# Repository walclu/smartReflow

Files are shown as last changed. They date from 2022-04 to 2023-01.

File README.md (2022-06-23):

# smartReflow
## Repository for STM32WB55 based reflow toaster oven controller

The smartReflowV2 is a STm32WB55 based toaster oven reflow controller for reflowing PCBs at home. 

## Features
- 2 SSR outputs
- 2 cooling fan outputs
- 2 MAX31855 temperature ADCs
- Buzzer
- Touch screen (Nextion 2.4" UART Display)
- Bluetooth low energy, onboard chip antenna with matching
- 2 virtual com ports 
- MATLAB data streaming
- EEPROM for storing custom profiles
- PLA drying mode

## Assembly
The PCB was made by JLCPCB and assembled by hand.
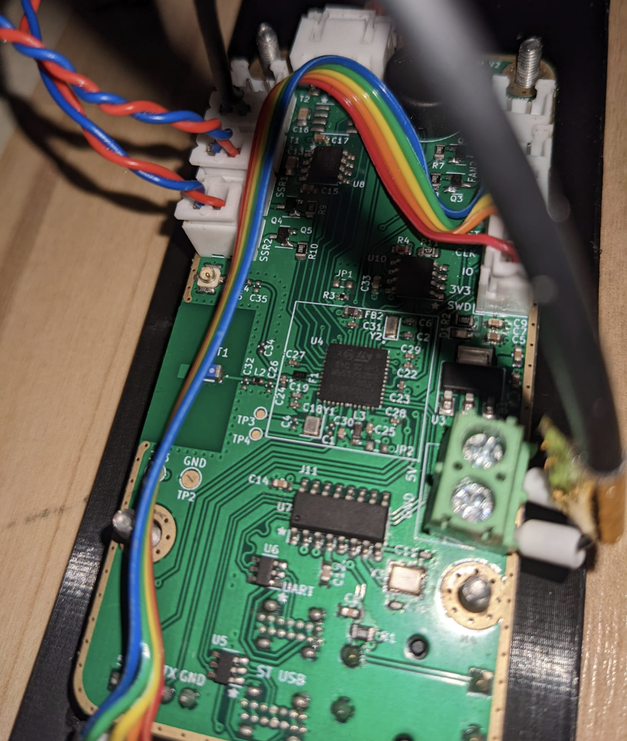
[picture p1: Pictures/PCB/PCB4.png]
Assembled PCB


## Results
The oven follows the desired temperature profile with only 5% of total error (Reflow state is a little bit delayed at the end).
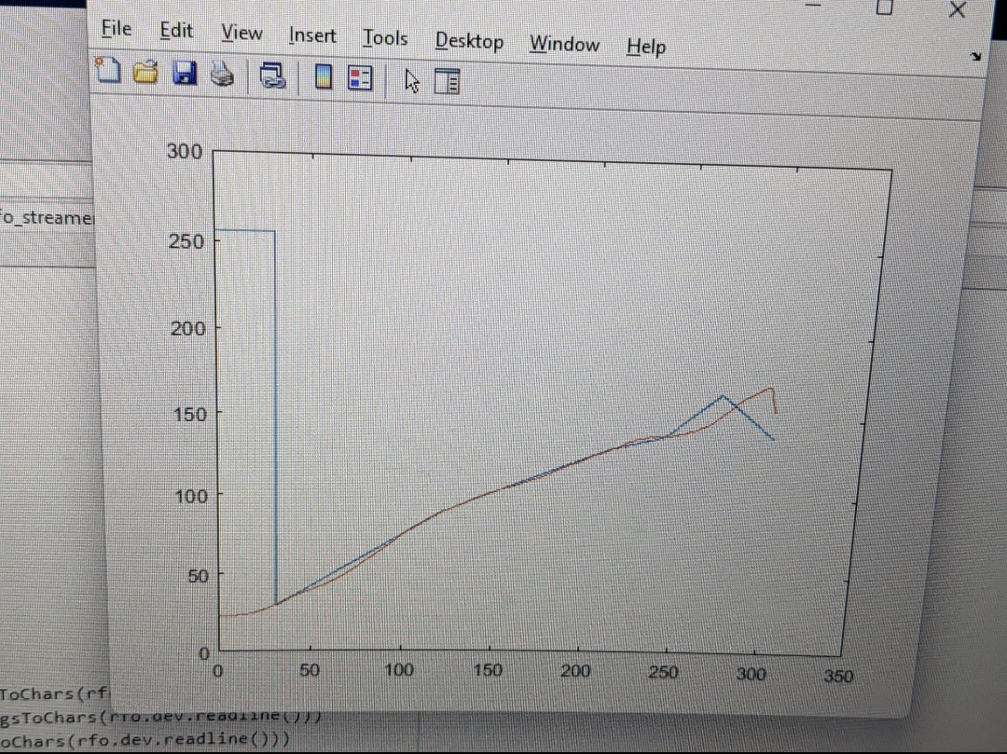
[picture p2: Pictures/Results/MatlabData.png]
matlab

QFN28 soldering results with 138 C paste profile. No need of rework had to be done.
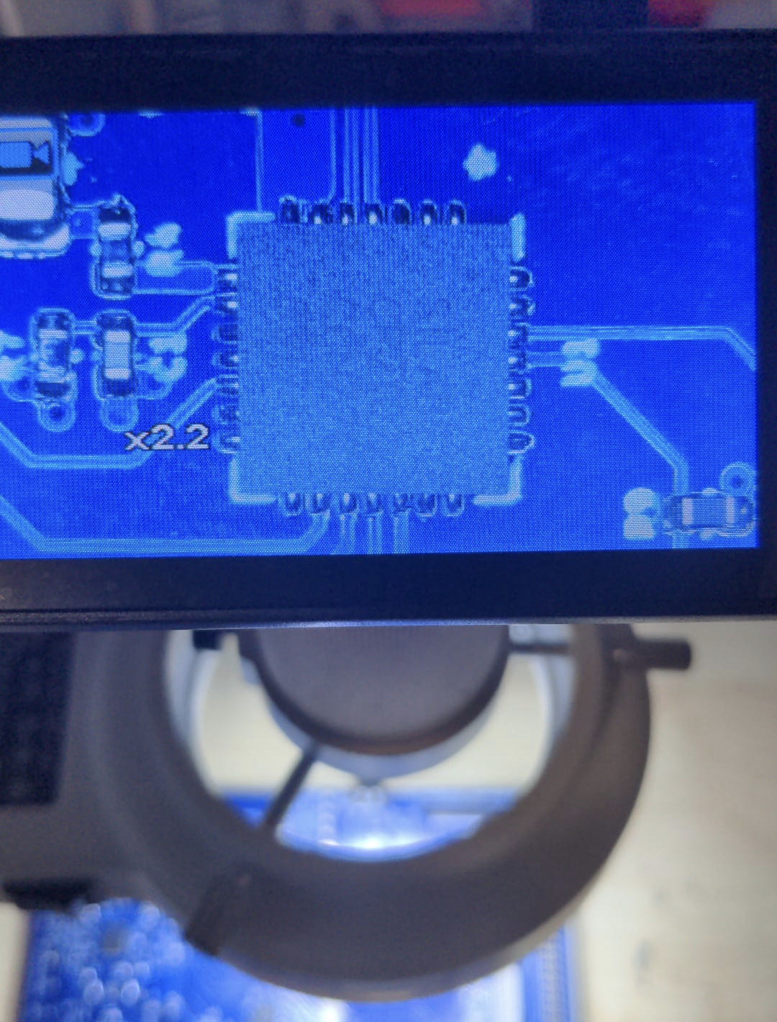
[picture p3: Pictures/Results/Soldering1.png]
qfn soldering

Finished oven
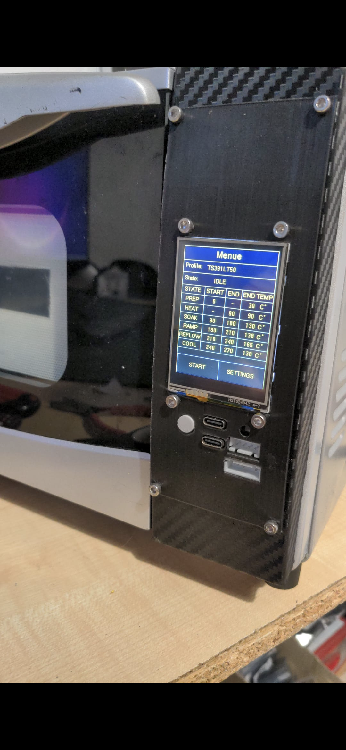
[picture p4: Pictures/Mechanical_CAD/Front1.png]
Oven front


## ToDos
- Bluetooth works, but an interface (i.e. app) is needed
- Firmware is hard to read
- PCB outline is too small (Nextion Display does not fit nicely onto it)
- EEPROM usage not implemented
- PID autotune code

## License
MIT

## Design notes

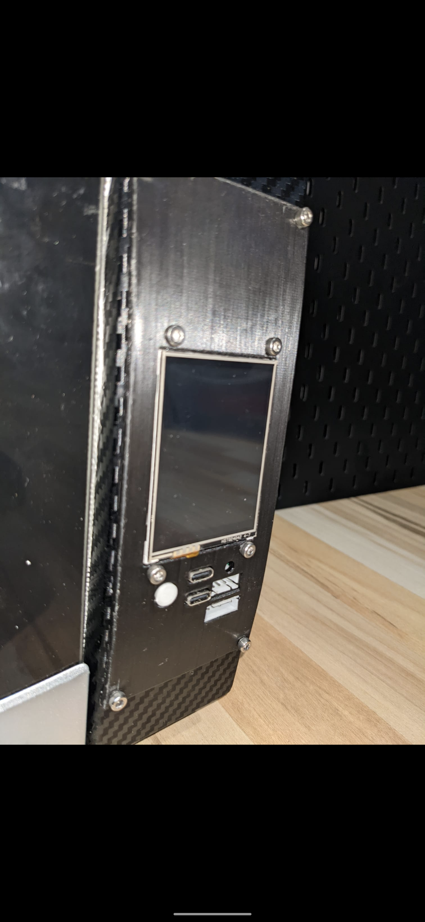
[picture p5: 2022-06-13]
Pictures/Mechanical_CAD/Front2.png

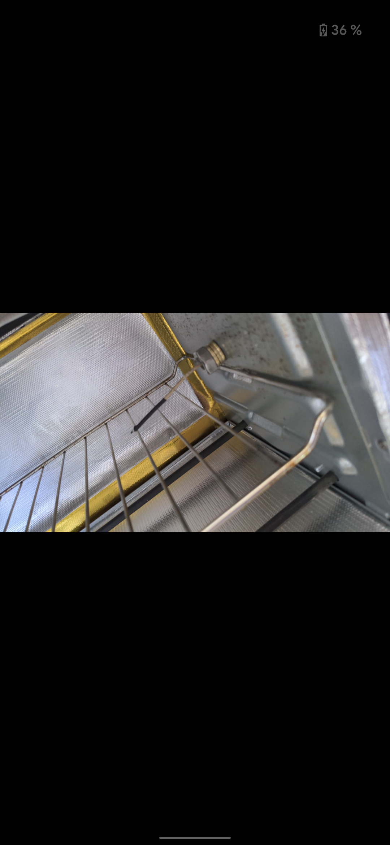
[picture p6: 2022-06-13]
Pictures/Mechanical_CAD/Tempsens.png

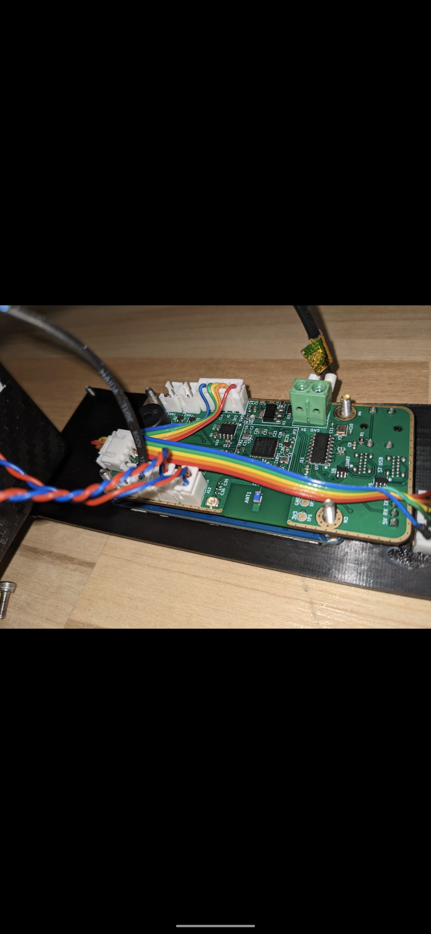
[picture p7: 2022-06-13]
Pictures/PCB/PCB3.png

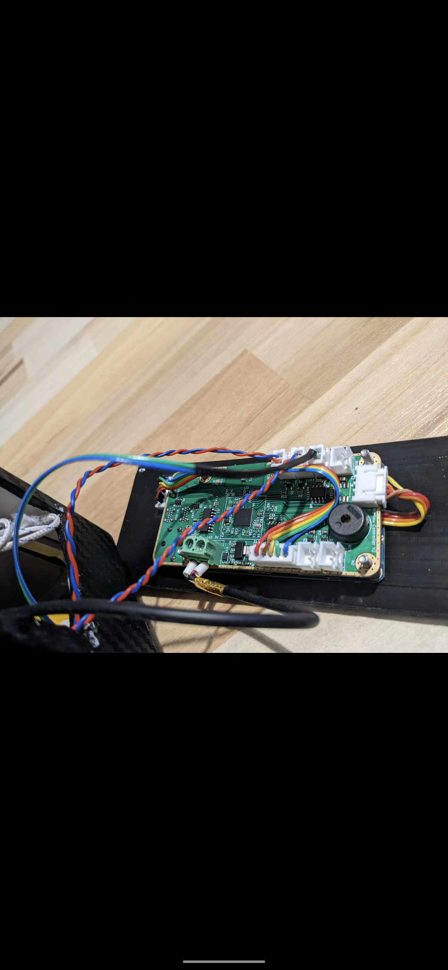
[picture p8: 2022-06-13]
Pictures/PCB/PCB5.png

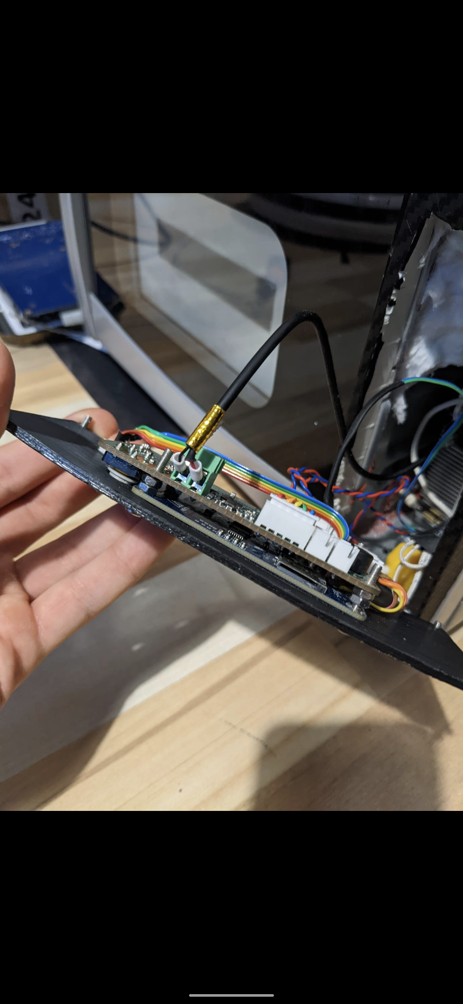
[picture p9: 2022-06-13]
Pictures/PCB/PCB7.png

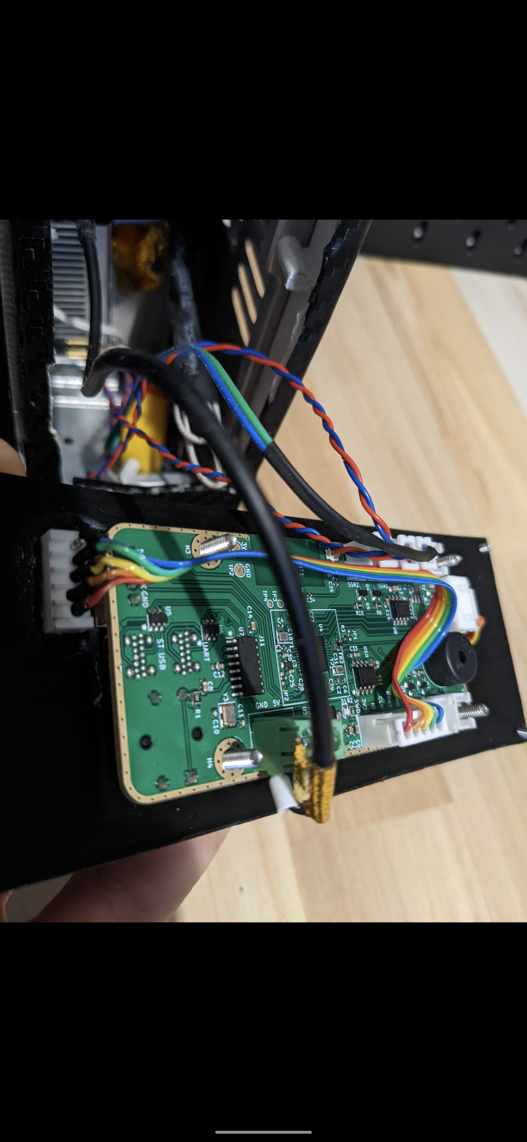
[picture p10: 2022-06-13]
Pictures/PCB/PCB6.png

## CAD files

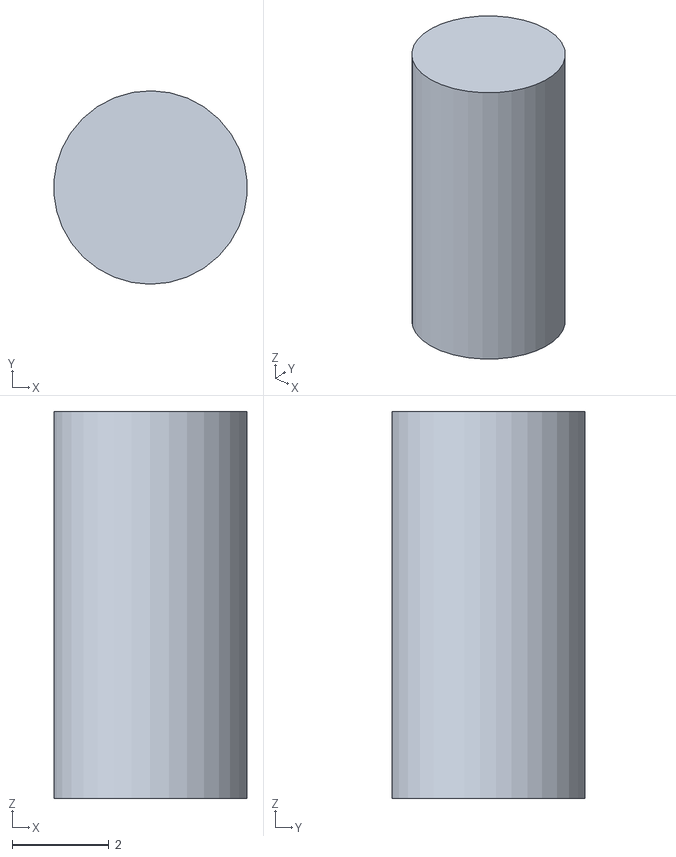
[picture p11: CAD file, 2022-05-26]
3D_CAD/led.stl
3.99 x 4.00 x 8.00

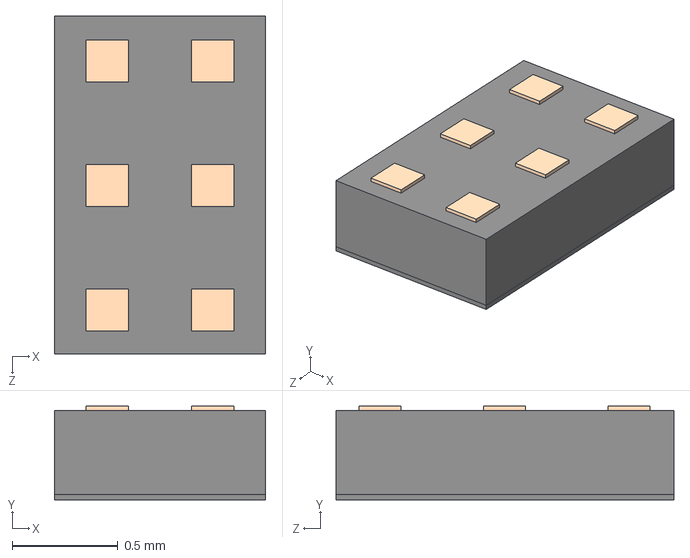
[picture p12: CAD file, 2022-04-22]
PCB/parts/rCv2LIB/3d.shapes/MLPF-WB55-01E3.stp
1.00 x 0.445 x 1.60 mm

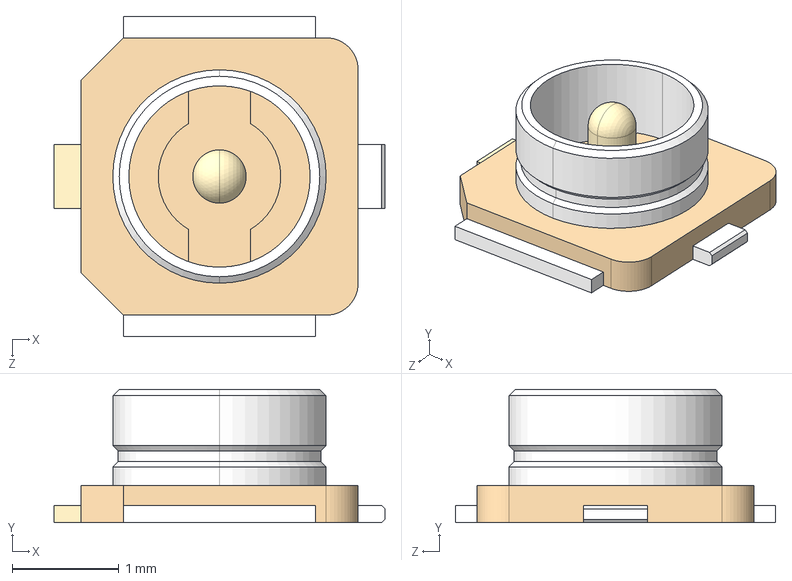
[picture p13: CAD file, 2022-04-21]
PCB/parts/rCv2LIB/A-1JB/3d.shapes/A-1JB.step
3.10 x 1.25 x 3.00 mm

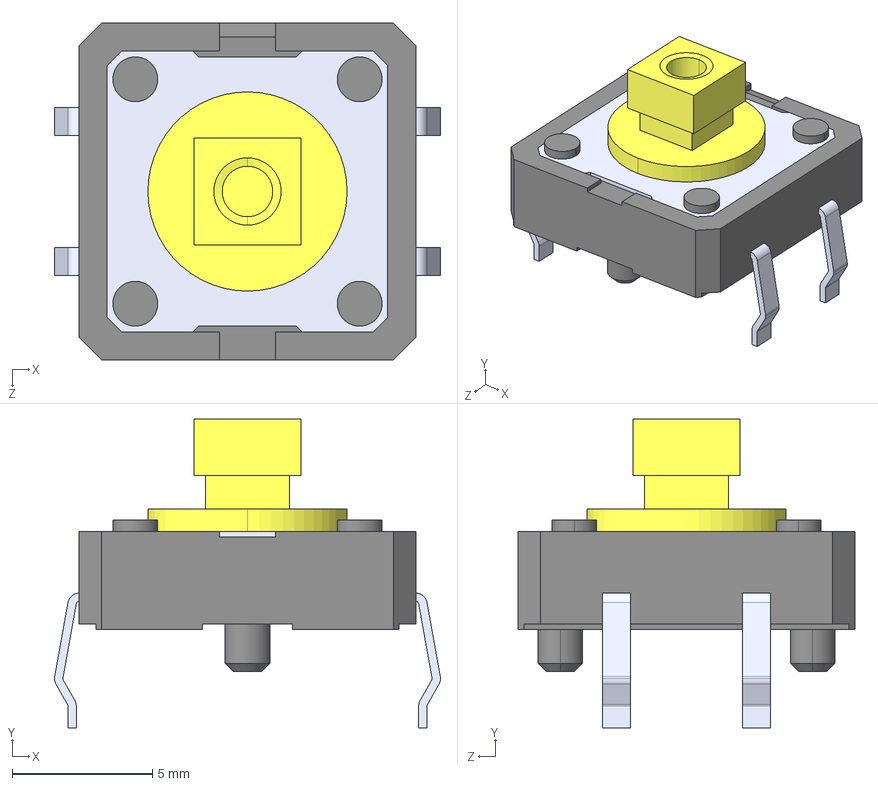
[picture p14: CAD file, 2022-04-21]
PCB/parts/rCv2LIB/B3F-4055/3d.shapes/B3F-4055.step
13.8 x 11.0 x 12.0 mm

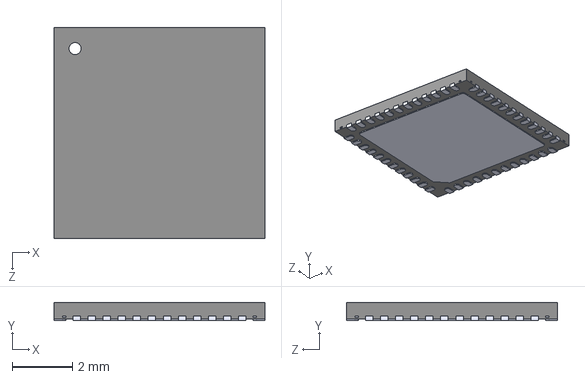
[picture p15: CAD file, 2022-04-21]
PCB/parts/rCv2LIB/STM32WB55CEU6TR/3dshapes/STM32WB55CEU6TR.step
7.00 x 0.6 x 7.00 mm

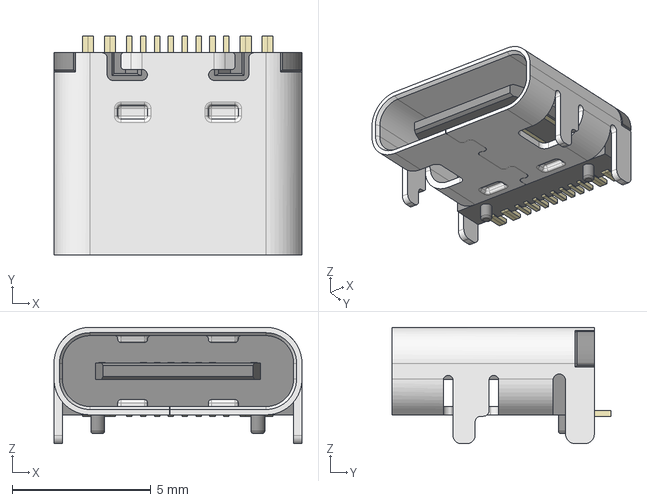
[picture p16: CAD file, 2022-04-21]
PCB/parts/rCv2LIB/TYPC/3d.shapes/HRO_TYPE-C-31-M-12.step
8.95 x 7.90 x 4.20 mm

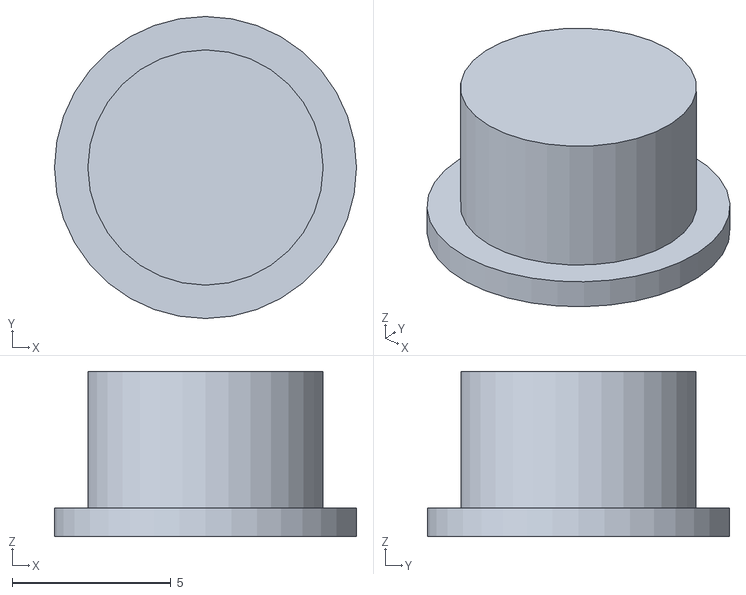
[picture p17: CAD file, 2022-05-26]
3D_CAD/button.stl
9.50 x 9.50 x 5.20

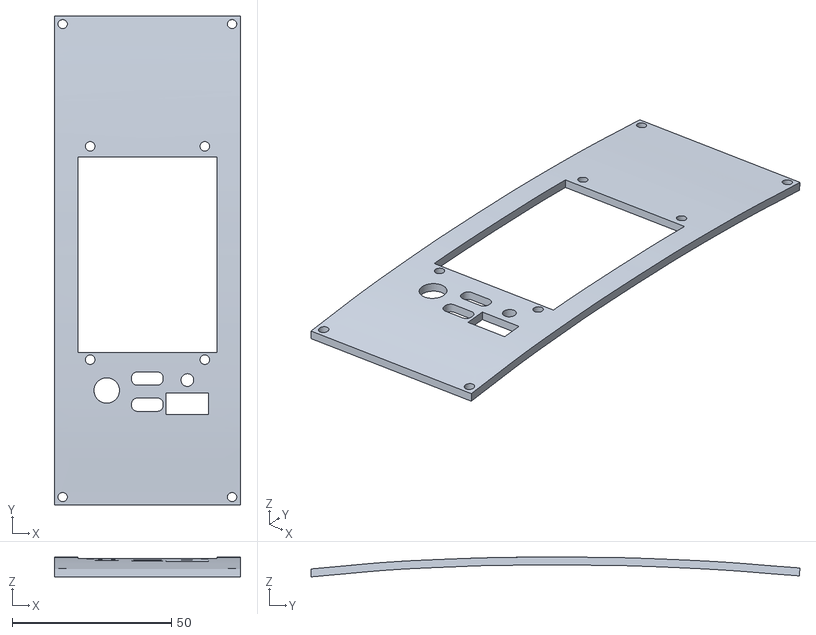
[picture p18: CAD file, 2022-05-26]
3D_CAD/smartReflowFront.stl
58.5 x 153.6 x 6.25

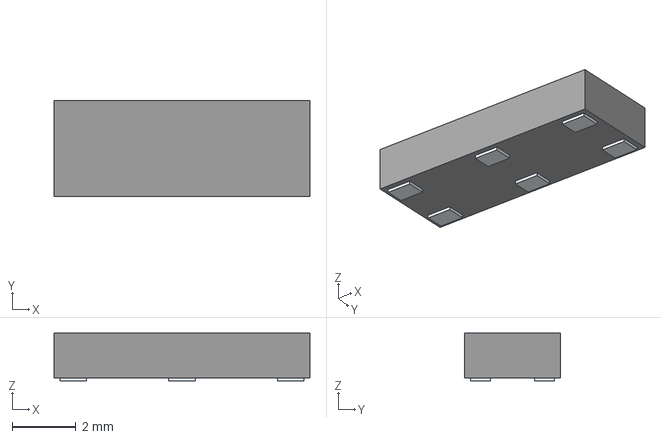
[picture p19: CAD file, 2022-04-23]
PCB/parts/rCv2LIB/M830520/3d.shapes/M830520.stp
8.00 x 3.00 x 1.50 mm
Pins

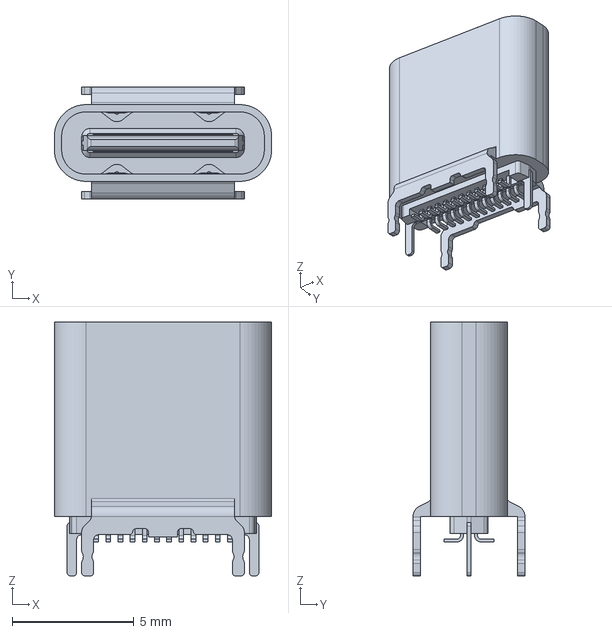
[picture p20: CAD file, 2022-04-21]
PCB/parts/rCv2LIB/3d.shapes/2047110001.stp
8.94 x 4.60 x 10.4 mm

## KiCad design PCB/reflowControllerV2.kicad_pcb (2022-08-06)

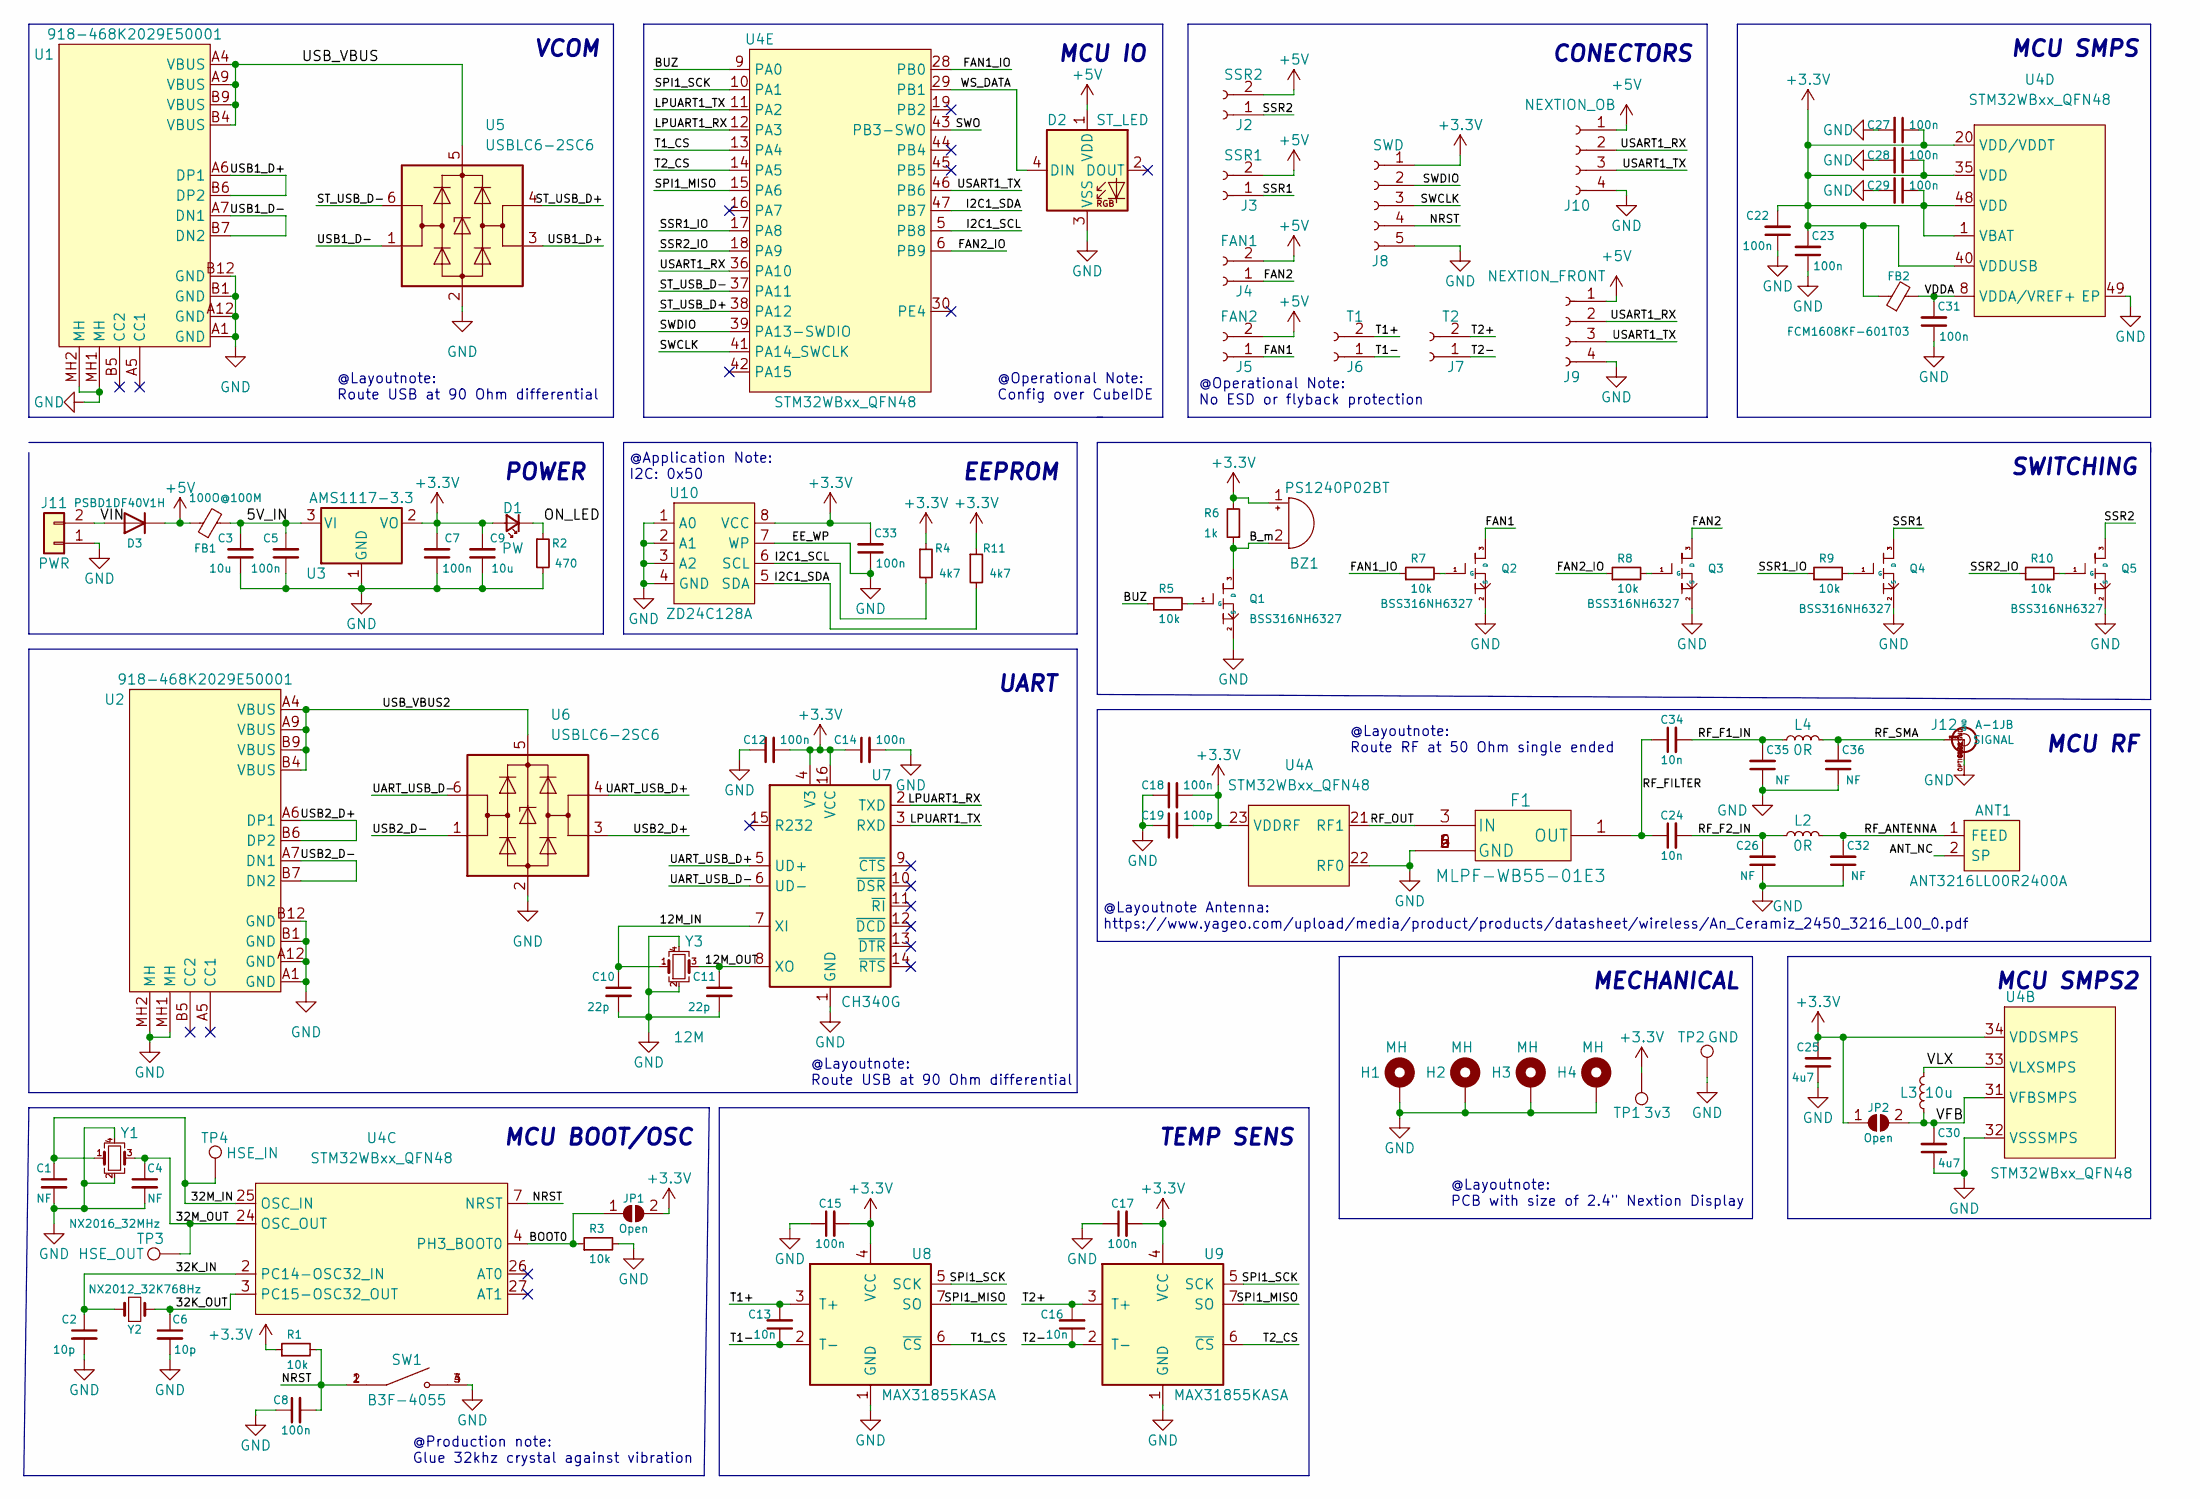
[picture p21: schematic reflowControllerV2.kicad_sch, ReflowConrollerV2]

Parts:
ANT1: ANT3216LL00R2400A; Mouser Part Number 603-ANT3216LL00R2400
BZ1: PS1240P02BT; Buzzer_TDK_PS1240P02BT_D12.2mm_H6.5mm
C1, C4, C26, C32, C35, C36: NF; C_0402_1005Metric
C2, C6: 10p; C_0402_1005Metric
C3, C9: 10u; C_0603_1608Metric
C5, C7, C8, C12, C14, C15, C17, C33: 100n; C_0603_1608Metric
C10, C11: 22p; C_0402_1005Metric
C13, C16: 10n; C_0805_2012Metric
C18, C22, C23, C27, C28, C29, C31: 100n; C_0402_1005Metric
C19: 100p; C_0402_1005Metric
C24, C34: 10n; C_0402_1005Metric
C25, C30: 4u7; C_0402_1005Metric
D1: PW; LED_0603_1608Metric
D2: ST_LED; LED_WS2812B_PLCC4_5.0x5.0mm_P3.2mm
D3: PSBD1DF40V1H; D_SOD-123F
F1: MLPF-WB55-01E3
FB1: 100O@100M; L_0603_1608Metric
FB2: FCM1608KF-601T03; L_0603_1608Metric
H1, H2, H3, H4: MH; MountingHole_3.2mm_M3_Pad_Via
J2: SSR2; JST_254_2P_V
J3: SSR1; JST_254_2P_V
J4: FAN1; JST_254_2P_V
J5: FAN2; JST_254_2P_V
J6: T1; JST_254_2P_V
J7: T2; JST_254_2P_V
J8: SWD; JST_254_5P_V
J9: NEXTION_FRONT; JST_254_4P_V
J10: NEXTION_OB; JST_254_4P_H
J11: PWR; TerminalBlock_Phoenix_MKDS-1,5-2_1x02_P5.00mm_Horizontal
J12: A-1JB; AMPHENOL_A-1JB
JP1, JP2: Open; R_0603_1608Metric
L2, L4: 0R; L_0402_1005Metric
L3: 10u; L_0603_1608Metric
Q1, Q2, Q3, Q4, Q5: BSS316NH6327; SOT-23
R1, R5, R7, R8, R9, R10: 10k; R_0603_1608Metric
R2: 470; R_0603_1608Metric
R3: 10k; R_0402_1005Metric
R4, R11: 4k7; R_0603_1608Metric
R6: 1k; R_0603_1608Metric
SW1: B3F-4055; SW_B3F-4055; PARTREV A070-E1-08
TP1: 3v3; TestPoint_Pad_D2.0mm
TP2: GND; TestPoint_Pad_D2.0mm
TP3: HSE_OUT; TestPoint_Pad_D1.0mm
TP4: HSE_IN; TestPoint_Pad_D1.0mm
U1, U2: 918-468K2029E50001
U3: AMS1117-3.3; SOT-223-3_TabPin2
U4: STM32WBxx_QFN48; QFN50P700X700X60-49N
U5, U6: USBLC6-2SC6; SOT-23-6
U7: CH340G; SOIC-16_3.9x9.9mm_P1.27mm
U8, U9: MAX31855KASA; SOIC-8_3.9x4.9mm_P1.27mm
U10: ZD24C128A; SOP-8_3.9x4.9mm_P1.27mm
Y1: NX2016_32MHz; Crystal_SMD_2016-4Pin_2.0x1.6mm
Y2: NX2012_32K768Hz; Crystal_SMD_2012-2Pin_2.0x1.2mm_HandSoldering
Y3: 12M; Crystal_SMD_3225-4Pin_3.2x2.5mm

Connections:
+3V3: BZ1.1 (-), C7.2, C9.2, C12.2, C14.1, C15.2, C17.2, C18.2, C19.2, C22.2, C23.2, C25.2, C27.1, C28.1, C29.1, C33.2, D1.2 (A), FB2.1, J8.1, JP1.2 (B), JP2.1 (A), R1.1, R4.1, R6.2, R11.1, TP1.1, U3.2 (VO), U4.1 (VBAT), U4.20 (VDD/VDDT), U4.23 (VDDRF), U4.34 (VDDSMPS), U4.35 (VDD), U4.40 (VDDUSB), U4.48 (VDD), U7.4 (V3), U7.16 (VCC), U8.4 (VCC), U9.4 (VCC), U10.8 (VCC)
+5V: D2.1 (VDD), D3.1 (K), FB1.1, J2.2, J3.2, J4.2, J5.2, J9.1, J10.1
/5V_IN: C3.2, C5.2, FB1.2, U3.3 (VI)
/12M_IN: C10.1, U7.7 (XI), Y3.1
/12M_OUT: C11.1, U7.8 (XO), Y3.3
/32K_IN: C2.1, U4.2 (PC14-OSC32_IN), Y2.1
/32K_OUT: C6.1, U4.3 (PC15-OSC32_OUT), Y2.2
/32M_IN: C1.1, TP4.1, U4.25 (OSC_IN), Y1.1
/32M_OUT: C4.1, TP3.1, U4.24 (OSC_OUT), Y1.3
/ANT_NC: ANT1.2 (SP)
/BOOT0: JP1.1 (A), R3.1, U4.4 (PH3_BOOT0)
/BUZ: R5.1, U4.9 (PA0)
/B_m: BZ1.2 (+), Q1.3 (D), R6.1
/FAN1: J5.1, Q2.3 (D)
/FAN1_IO: R7.1, U4.28 (PB0)
/FAN2: J4.1, Q3.3 (D)
/FAN2_IO: R8.1, U4.6 (PB9)
/I2C1_SCL: R4.2, U4.5 (PB8), U10.6 (SCL)
/I2C1_SDA: R11.2, U4.47 (PB7), U10.5 (SDA)
/LPUART1_RX: U4.12 (PA3), U7.2 (TXD)
/LPUART1_TX: U4.11 (PA2), U7.3 (RXD)
/NRST: C8.2, J8.4, R1.2, SW1.1, SW1.2, U4.7 (NRST)
/ON_LED: D1.1 (K), R2.1
/RF_ANTENNA: ANT1.1 (FEED), C32.2, L2.2
/RF_F1_IN: C34.2, C35.2, L4.1
/RF_F2_IN: C24.2, C26.2, L2.1
/RF_FILTER: C24.1, C34.1, F1.1 (OUT)
/RF_OUT: F1.3 (IN), U4.21 (RF1)
/RF_SMA: C36.2, J12.SIGNAL, L4.2
/SPI1_MISO: U4.15 (PA6), U8.7 (SO), U9.7 (SO)
/SPI1_SCK: U4.10 (PA1), U8.5 (SCK), U9.5 (SCK)
/SSR1: J3.1, Q4.3 (D)
/SSR1_IO: R9.1, U4.17 (PA8)
/SSR2: J2.1, Q5.3 (D)
/SSR2_IO: R10.1, U4.18 (PA9)
/ST_USB_D+: U4.38 (PA12), U5.4 (I/O2)
/ST_USB_D-: U4.37 (PA11), U5.6 (I/O1)
/SWCLK: J8.3, U4.41 (PA14_SWCLK)
/SWDIO: J8.2, U4.39 (PA13-SWDIO)
/SWO: U4.43 (PB3-SWO)
/T1+: C13.2, J6.2, U8.3 (T+)
/T1-: C13.1, J6.1, U8.2 (T-)
/T1_CS: U4.13 (PA4), U8.6 (~CS)
/T2+: C16.2, J7.2, U9.3 (T+)
/T2-: C16.1, J7.1, U9.2 (T-)
/T2_CS: U4.14 (PA5), U9.6 (~CS)
/UART_USB_D+: U6.4 (I/O2), U7.5 (UD+)
/UART_USB_D-: U6.6 (I/O1), U7.6 (UD-)
/USART1_RX: J9.2, J10.2, U4.36 (PA10)
/USART1_TX: J9.3, J10.3, U4.46 (PB6)
/USB1_D+: U1.A6 (DP1), U1.B6 (DP2), U5.3 (I/O2)
/USB1_D-: U1.A7 (DN1), U1.B7 (DN2), U5.1 (I/O1)
/USB2_D+: U2.A6 (DP1), U2.B6 (DP2), U6.3 (I/O2)
/USB2_D-: U2.A7 (DN1), U2.B7 (DN2), U6.1 (I/O1)
/USB_VBUS: U1.A4 (VBUS), U1.A9 (VBUS), U1.B4 (VBUS), U1.B9 (VBUS), U5.5 (VBUS)
/USB_VBUS2: U2.A4 (VBUS), U2.A9 (VBUS), U2.B4 (VBUS), U2.B9 (VBUS), U6.5 (VBUS)
/VDDA: C31.2, FB2.2, U4.8 (VDDA/VREF+)
/VFB: C30.2, JP2.2 (B), L3.1, U4.31 (VFBSMPS)
/VIN: D3.2 (A), J11.2
/VLX: L3.2, U4.33 (VLXSMPS)
/WS_DATA: D2.4 (DIN), U4.29 (PB1)
GND: C1.2, C2.2, C3.1, C4.2, C5.1, C6.2, C7.1, C8.1, C9.1, C10.2, C11.2, C12.1, C14.2, C15.1, C17.1, C18.1, C19.1, C22.1, C23.1, C25.1, C26.1, C27.2, C28.2, C29.2, C30.1, C31.1, C32.1, C33.1, C35.1, C36.1, D2.3 (VSS), F1.2 (GND), F1.4 (GND), F1.5 (GND), F1.6 (GND), H1.1, H2.1, H3.1, H4.1, J8.5, J9.4, J10.4, J11.1, J12.GND1 (GND), J12.GND2 (GND), J12.OPTIONAL_GND (GND), Q1.2 (S), Q2.2 (S), Q3.2 (S), Q4.2 (S), Q5.2 (S), R2.2, R3.2, SW1.3, SW1.4, TP2.1, U1.A1 (GND), U1.A12 (GND), U1.B1 (GND), U1.B12 (GND), U1.MH1 (MH), U1.MH2 (MH), U2.A1 (GND), U2.A12 (GND), U2.B1 (GND), U2.B12 (GND), U2.MH1 (MH), U2.MH2 (MH), U3.1 (GND), U4.22 (RF0), U4.32 (VSSSMPS), U4.49 (EP), U5.2 (GND), U6.2 (GND), U7.1 (GND), U8.1 (GND), U9.1 (GND), U10.1 (A0), U10.2 (A1), U10.3 (A2), U10.4 (GND), U10.7 (WP), Y1.2, Y1.4, Y3.2, Y3.4
unnamed: Q1.1 (G), R5.2
unnamed: Q2.1 (G), R7.2
unnamed: Q3.1 (G), R8.2
unnamed: Q4.1 (G), R9.2
unnamed: Q5.1 (G), R10.2

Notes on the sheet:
EEPROM
MCU SMPS2
@Operational Note: No ESD or flyback protection
MECHANICAL
@Layoutnote: Route RF at 50 Ohm single ended
@Layoutnote: Route USB at 90 Ohm differential
TEMP SENS
@Layoutnote Antenna: https://www.yageo.com/upload/media/product/products/datasheet/wireless/An_Ceramiz_2450_3216_L00_0.pdf
SWITCHING
MCU BOOT/OSC
MCU IO
UART
CONECTORS
MCU SMPS
VCOM
@Production note: Glue 32khz crystal against vibration
@Operational Note: Config over CubeIDE
MCU RF
@Layoutnote: PCB with size of 2.4" Nextion Display
POWER
@Application Note: I2C: 0x50

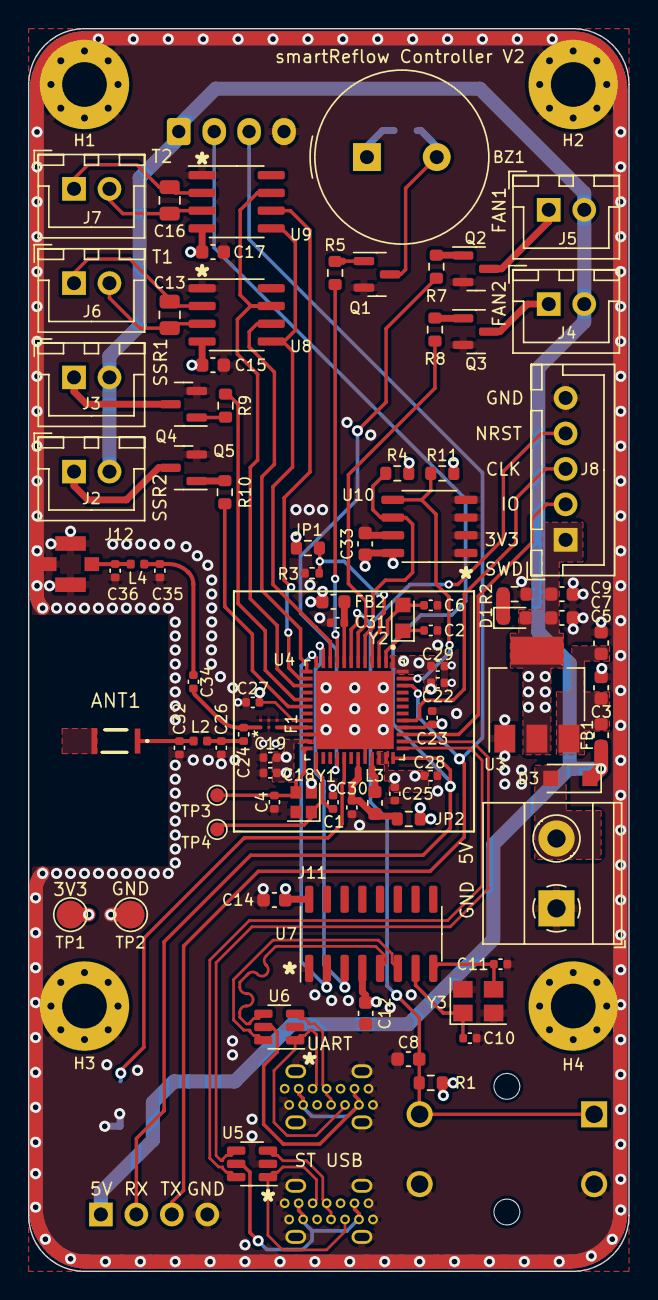
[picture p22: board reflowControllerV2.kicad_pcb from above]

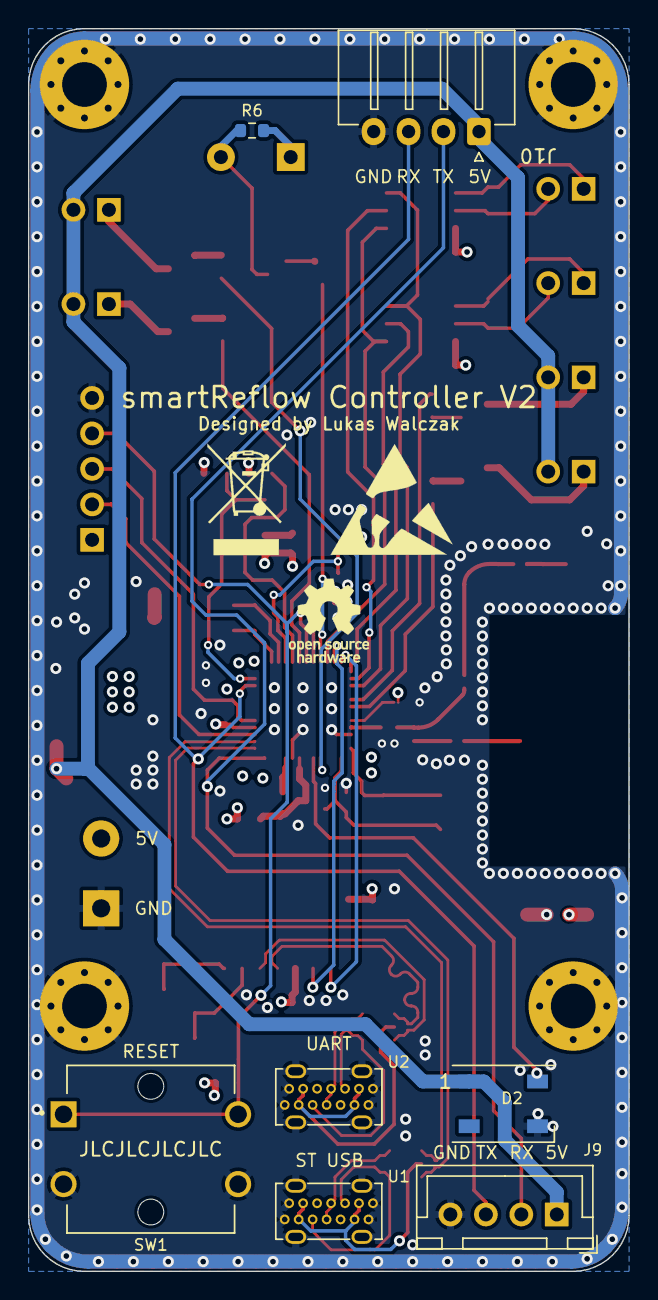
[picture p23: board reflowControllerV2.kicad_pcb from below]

Board: 4 copper layers, 43.0 x 89.0 mm, 96 parts (7 on the bottom side), 65 nets.

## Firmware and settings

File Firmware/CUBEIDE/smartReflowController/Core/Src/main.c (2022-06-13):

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
/* Includes ------------------------------------------------------------------*/
#include "main.h"

/* USER CODE BEGIN Includes */
#include "stdarg.h"
#include "string.h"
#include "stdbool.h"
#include "stdio.h"
#include "math.h"

#include "MAX31855.h"
#include "pid.h"
#include "nextion.h"
/* USER CODE END Includes */

/* USER CODE BEGIN PTD */

struct _rfo_t {

	UART_HandleTypeDef* uart;
	uint8_t rcv[20];
	uint8_t trm[20];

	SPI_HandleTypeDef* spi;

	uint16_t idx;
	bool print;

	TIM_HandleTypeDef* buzPwmTim;
	TIM_HandleTypeDef* buzElapsTim;

	TIM_HandleTypeDef* ssrTim;

	uint8_t ssr1Ch;
	uint8_t ssr2Ch;

	uint8_t numBeeps;
	uint8_t cntBeeps;

	uint8_t currentReflowState;
	float targetTemp;
	uint32_t elaps;

	bool dataRdy;
	uint8_t packetId;
	float temp;
	float dTemp;

	uint16_t dutyCycle;
	uint16_t pwmFreq;

	uint8_t currentPage;
	uint8_t currentMode;

};
typedef struct _rfo_t rfo_t;



char *rfoCmdLut[] = {"pwm -s --duty", "pwm -s --freq", "temp -m --cont",
		"start -p --nonleaded", "stop" ,"calibrate", "help"
};


struct _rfo_fsm_t {
	bool connected;
	bool streaming;
	uint8_t state;
};
typedef struct _rfo_fsm_t rfo_fsm_t;

enum _rfoStates {
	RFO_IDLE,
	RFO_PROCESS_CMD,
	RFO_PWM_SET_FREQ,
	RFO_PWM_SET_DUTY,
	RFO_GET_TEMP,
	RFO_START,
	RFO_STOP,
	RFO_TRANSMIT,
	RFO_CALIBRATE,
	RFO_RESET,
	RFO_HELP,
	RFO_STATES,
};

enum _reflowStates_t
{
	REFLOW_STATE_IDLE,
	REFLOW_STATE_DEBUG,
	REFLOW_STATE_PREPARE,
	REFLOW_STATE_PREHEAT,
	REFLOW_STATE_SOAK,
	REFLOW_STATE_RAMP,
	REFLOW_STATE_REFLOW,
	REFLOW_STATE_COOL,
	REFLOW_STATE_COMPLETE,
	REFLOW_STATE_TOO_HOT,
	REFLOW_STATE_PLA,
	REFLOW_STATES
};

enum _dp_page_ids {
	DP_LOADING,
	DP_MAIN,
	DP_SETTINGS,
	DP_REFLOW,
	DP_FILAMENT,
	DP_MAINPLA,
	DP_PAGES
};

enum _rfo_modes {
	RFO_MODE_REFLOW,
	RFO_MODE_PLA,
	RFO_MODES
};
/* USER CODE END PTD */

/* USER CODE BEGIN PD */
#define MCU_FREQ_KHZ 64000
#define RFO_DEFAULT_DUTY 50
#define RFO_DEFAULT_PWM_FREQ_KHZ 10

#define SAMPLE_TIME 0.5f
#define DEBUG 0
/* USER CODE END PD */

/* USER CODE BEGIN PM */

#define _RFO_INIT(_dev, _uartHandle, _spiHandle, _buzPwmTim, _buzElapsTim, _ssrTim, _dutyCycle, _pwmFreq) \
		do{ \
			(_dev)-> uart =  _uartHandle; \
			(_dev)-> spi = _spiHandle; \
			(_dev)-> buzPwmTim = _buzPwmTim; \
			(_dev)-> buzElapsTim = _buzElapsTim; \
			(_dev)-> ssrTim = _ssrTim; \
			(_dev)-> numBeeps = 0; \
			(_dev)-> cntBeeps = 0; \
			(_dev)-> idx = 0; \
			(_dev)-> currentReflowState = REFLOW_STATE_IDLE; \
			(_dev)-> elaps = 0; \
			(_dev)-> targetTemp = 0; \
			(_dev)-> dataRdy = false; \
			(_dev)-> packetId = 0; \
			(_dev)-> temp = 0; \
			(_dev)-> dutyCycle = _dutyCycle; \
			(_dev)-> pwmFreq = _pwmFreq; \
			(_dev)-> currentPage = DP_LOADING; \
			(_dev)-> currentMode = RFO_MODE_REFLOW; \
		} while(0)

#define _RFO_FSM_INIT(_fsm) \
		do{ \
			(_fsm)->state = RFO_IDLE; \
			(_fsm)->connected = false; \
			(_fsm)->streaming = false; \
		} while(0)


#define _RFO_PERIPHERAL_INIT() \
		do{ \
			HAL_UART_Receive_IT(&hlpuart1, dev->rcv, 1);\
			__HAL_TIM_SET_COMPARE(&htim2, TIM_CHANNEL_1, 0);\
			HAL_TIM_PWM_Start(&htim2, TIM_CHANNEL_1);\
			__HAL_TIM_SET_COMPARE(&htim1, TIM_CHANNEL_1, 0);\
			__HAL_TIM_SET_COMPARE(&htim1, TIM_CHANNEL_2, 0);\
			HAL_TIM_PWM_Start(&htim1, TIM_CHANNEL_1);\
			HAL_TIM_PWM_Start(&htim1, TIM_CHANNEL_2);\
		} while(0)

/* USER CODE END PM */

I2C_HandleTypeDef hi2c1;

UART_HandleTypeDef hlpuart1;
UART_HandleTypeDef huart1;

SPI_HandleTypeDef hspi1;

TIM_HandleTypeDef htim1;
TIM_HandleTypeDef htim2;
TIM_HandleTypeDef htim16;
TIM_HandleTypeDef htim17;

/* USER CODE BEGIN PV */
rfo_t rfoDevObj;
rfo_t* dev = &rfoDevObj;

rfo_fsm_t rfoFsmObj;
rfo_fsm_t* fsm = & rfoFsmObj;

max31855_t max81855Obj;
max31855_t* tempSens = &max81855Obj;

PIDController pidObj;

PIDController* pid = &pidObj;

nextion_t dpObj;

nextion_t* dp = &dpObj;

/*
Lead-Free Reflow Curve
======================
Temperature (Degree Celcius)
245-|                                               x  x
    |                                            x   |     x
    |                                         x      |        x
    |                                      x         |           x
130-|                                   x            |              x
    |                              x    |            |              |   x
    |                         x         |            |              |       x
    |                    x              |            |              |
 90-|               x                   |            |              |
    |             x |                   |            |              |
    |           x   |                   |            |              |
    |         x     |                   |            |              |
    |       x       |                   |            |              |
    |     x         |                   |            |              |
    |   x           |                   |            |              |
30 -| x             |                   |            |              |
    |  <  90 s  >|<          90 s      >| <   30   > |
    | Preheat Stage |   Soaking Stage   | Ramp Stage |              | Cool
 0  |_ _ _ _ _ _ _ _|_ _ _ _ _ _ _ _ _ _|_ _ _ _ _ _ |_ _ _ _ _ _ _ |_ _ _ _ _
                                                               Time (Seconds)
 */

const float PREHEAT_START_TIME  =		0;
const float PREHEAT_DURATION	=		90.f;
const float PREHEAT_START_TEMP 	=		30.f;
const float PREHEAT_END_TEMP 	=		90.f;

const float SOAK_START_TIME 	=		PREHEAT_START_TIME+PREHEAT_DURATION+SAMPLE_TIME;
const float SOAK_DURATION 		=		90.f;
const float SOAK_START_TEMP 	=		90.f;
const float SOAK_END_TEMP 		=		130.f;

const float RAMP_START_TIME 	=		SOAK_START_TIME+SOAK_DURATION+SAMPLE_TIME;
const float RAMP_DURATION 		=		30.f;
const float RAMP_START_TEMP 	=		130.f;
const float RAMP_END_TEMP 		=		138.f;

const float REFLOW_START_TIME 	=		RAMP_START_TIME+RAMP_DURATION+SAMPLE_TIME;
const float REFLOW_DURATION		=		30.f;
const float REFLOW_START_TEMP 	=		138.f;
const float REFLOW_END_TEMP 	=		165.f;

const float COOL_START_TIME 	=		REFLOW_START_TIME + REFLOW_DURATION+SAMPLE_TIME;
const float COOL_DURATION		=		30.f;
const float COOL_END_TEMP 		=		138.f;

const float PREHEAT_TEMP_INCREASE 	=	((PREHEAT_END_TEMP-PREHEAT_START_TEMP)/PREHEAT_DURATION);
const float SOAK_TEMP_INCREASE 		= 	((SOAK_END_TEMP-SOAK_START_TEMP)/SOAK_DURATION);
const float RAMP_TEMP_INCREASE 		=	((RAMP_END_TEMP-RAMP_START_TEMP)/RAMP_DURATION);
const float REFLOW_TEMP_INCREASE 	=	((REFLOW_END_TEMP-REFLOW_START_TEMP)/RAMP_DURATION);
const float COOL_TEMP_DECREASE 		=	((REFLOW_END_TEMP-COOL_END_TEMP)/COOL_DURATION);

const float kP 					=		39;
const float kI 					=		1;
const float kD 					=		31;
const float tau			    	=		0.2f;
const float limMin 				=   	0;
const float limMax 				=   	256;
const float limMinInt 			=   	-60.0f;
const float limMaxInt 			=   	60.0f;

const float plaKp 					=		9.f;
const float plaKi 					=		.0002f;
const float plaKd 					=		2.2f;

const float plaTemp = 45;
const float plaDuration = 600;

const int reflowARR = 256;
const int plaARR = 512;
/* USER CODE END PV */

void SystemClock_Config(void);
void PeriphCommonClock_Config(void);
static void MX_GPIO_Init(void);
static void MX_I2C1_Init(void);
static void MX_LPUART1_UART_Init(void);
static void MX_USART1_UART_Init(void);
static void MX_SPI1_Init(void);
static void MX_TIM1_Init(void);
static void MX_TIM2_Init(void);
static void MX_TIM16_Init(void);
static void MX_TIM17_Init(void);
static void MX_NVIC_Init(void);
/* USER CODE BEGIN PFP */
void clear_buffer(uint8_t* buf, uint32_t len);
void beep_IT(rfo_t *dev, uint8_t numBeeps);
/* USER CODE END PFP */

/* USER CODE BEGIN 0 */
void clear_buffer(uint8_t* buf, uint32_t len)
{
	for(int z = 0; z < len; z++)
	{
		buf[z] = '\0';
	}
}

void beep_IT(rfo_t* dev, uint8_t numBeeps) {
	dev->numBeeps = numBeeps;
	dev->cntBeeps = 0;
	__HAL_TIM_SET_COMPARE(dev->buzPwmTim, TIM_CHANNEL_1, 2);
	__HAL_TIM_CLEAR_FLAG(dev->buzElapsTim, TIM_SR_UIF);
	HAL_TIM_Base_Start_IT(dev->buzElapsTim);

}

void delay_us (uint16_t us)
{
	HAL_TIM_Base_Start(&htim17);
	__HAL_TIM_SET_COUNTER(&htim17,0);  // set the counter value a 0
	(&htim17)->Instance->PSC = 64-1;
	(&htim17)->Instance->ARR = 64000-1;
	while (__HAL_TIM_GET_COUNTER(&htim17) < us);  // wait for the counter to reach the us input in the parameter
	HAL_TIM_Base_Stop(&htim17);
	(&htim17)->Instance->PSC = 64000-1;
	(&htim17)->Instance->ARR = 50;
}
/* USER CODE END 0 */

/**
 * @brief  The application entry point.
 * @retval int
 */
int main(void)
{
	/* MCU Configuration--------------------------------------------------------*/

	/* Reset of all peripherals, Initializes the Flash interface and the Systick. */
	HAL_Init();

	/* Configure the system clock */
	SystemClock_Config();

	/* Configure the peripherals common clocks */
	PeriphCommonClock_Config();

	/* Initialize all configured peripherals */
	MX_GPIO_Init();
	MX_I2C1_Init();
	MX_LPUART1_UART_Init();
	MX_USART1_UART_Init();
	MX_SPI1_Init();
	MX_TIM1_Init();
	MX_TIM2_Init();
	MX_TIM16_Init();
	MX_TIM17_Init();

	/* Initialize interrupts */
	MX_NVIC_Init();
	/* USER CODE BEGIN 2 */
	_RFO_INIT(dev, &hlpuart1, &hspi1 ,&htim2, &htim17, &htim2, RFO_DEFAULT_DUTY, RFO_DEFAULT_PWM_FREQ_KHZ);
	_RFO_FSM_INIT(fsm);

	HAL_UART_Receive(&huart1, dp->rcv, 50, 1000); // Resets UART buffers, so isr is not fired on boot
	HAL_UART_Receive_IT(&huart1, dp->rcv, 4);
	nextion_init(dp, &huart1);
	char buf[100];

	dp->write_id_val(dp, "j0", 0);

	_RFO_PERIPHERAL_INIT();

	MAX31855_init(tempSens, T1_CS_GPIO_Port, T1_CS_Pin, &hspi1);

	PIDController_Init(pid, kP, kI, kD, SAMPLE_TIME, tau, limMin, limMax, limMinInt, limMaxInt);

	dp->write_id_val(dp, "j0", 100);

	dp->write(dp, "page main");
	dev->currentPage = DP_MAIN;
	nextion_print_page(dp);
	beep_IT(dev,2);


	/* USER CODE END 2 */

	/* Infinite loop */
	/* USER CODE BEGIN WHILE */
	while (1)
	{
		/* USER CODE END WHILE */

		/* USER CODE BEGIN 3 */
		switch(fsm->state)
		{

		case RFO_IDLE:
			break;

		case RFO_PROCESS_CMD:
			if(dev->rcv[0] == '\r') {
				HAL_UART_Transmit(dev->uart, (uint8_t*)"\r\n", 2 , 100);
				buf[dev->idx] = '\0';
				for(int i = 0; i < 7; i++) {
					if(!strcmp(buf, rfoCmdLut[i]))
					{
						switch(i)
						{
						case 0:
							fsm->state = RFO_PWM_SET_DUTY;
							break;
						case 1:
							fsm->state = RFO_PWM_SET_FREQ;
							break;
						case 2:
							fsm->state = RFO_GET_TEMP;
							beep_IT(dev, 2);
							break;
						case 3:
							beep_IT(dev, 3);
							PIDController_Init(pid, kP, kI, kD, SAMPLE_TIME, tau, limMin, limMax, limMinInt, limMaxInt);
							__HAL_TIM_SET_AUTORELOAD(&htim1, reflowARR);
							fsm->state = RFO_START;
							dp->write(dp, "page reflow");
							dp->write_id_str(dp, "conState", "Connected");
							dp->write_id_str(dp, "reflowState", "Prepare");
							dp->write_id_val(dp, "reflowProgress", 0);
							dev->currentReflowState = REFLOW_STATE_PREPARE;
							HAL_TIM_Base_Start_IT(&htim16);
							break;
						case 4:
							fsm->state = RFO_STOP;
							break;
						case 5:
							fsm->state = RFO_CALIBRATE;
							break;
						case 6:
							fsm->state = RFO_HELP;
							break;
						default:
							break;
						}
						dev->idx = 0;
						break;
					}

				}

				if(fsm->state == RFO_PROCESS_CMD) {

					fsm->state = RFO_IDLE;

				}
				dev->idx = 0;
				clear_buffer((uint8_t*)buf, 100);

			}


			else if(dev->rcv[0] == '\177') {
				if(dev->idx > 0)
				{
					buf[dev->idx-1] = '\0';
					dev->idx -= 1;
					fsm->state = RFO_IDLE;
				}
			}

			else {
				buf[dev->idx] = dev->rcv[0];
				dev->idx += 1;
				clear_buffer((dev->rcv), 20);
				fsm->state = RFO_IDLE;
			}

			break;


		case RFO_PWM_SET_DUTY:
			__NOP();
			break;

		case RFO_PWM_SET_FREQ:
			__NOP();
			break;

		case RFO_GET_TEMP:
			__NOP();
			HAL_TIM_Base_Start_IT(&htim16);
			fsm->state = RFO_TRANSMIT;
			break;

		case RFO_START:
			__NOP();
			if(dev->dataRdy) {
				dev->dataRdy = false;

				PIDController_Update(pid, dev->targetTemp, dev->temp);

				__HAL_TIM_SET_COMPARE(&htim1, TIM_CHANNEL_1, pid->out);
				__HAL_TIM_SET_COMPARE(&htim1, TIM_CHANNEL_2, pid->out);

				sprintf(buf, "%.2f\n", dev->temp);
				HAL_UART_Transmit(dev->uart, (uint8_t*)buf, strlen(buf), 100);

				sprintf(buf, "%.2f\n", dev->targetTemp);
				HAL_UART_Transmit(dev->uart, (uint8_t*)buf, strlen(buf), 100);

				sprintf(buf, "%.2f\n", pid->out);
				HAL_UART_Transmit(dev->uart, (uint8_t*)buf, strlen(buf), 100);

			}
			break;

		case RFO_TRANSMIT:
			if(dev->dataRdy) {
				dev->dataRdy = false;
				sprintf(buf, "Temp is: %.2f\r\n", dev->temp);
				HAL_UART_Transmit(dev->uart, (uint8_t*)buf, strlen(buf), 100);
			}
			break;

		case RFO_STOP:
			break;

		case RFO_HELP:
			__NOP();
			sprintf(buf, "Help Page for RFO\r\n");
			HAL_UART_Transmit(dev->uart, (uint8_t*)buf, strlen(buf), 100);
			sprintf(buf, "Commands: ");
			HAL_UART_Transmit(dev->uart, (uint8_t*)buf, strlen(buf), 100);
			sprintf(buf, "pwm -<OPTION> --<INSTRUCTION>\r\n");
			HAL_UART_Transmit(dev->uart, (uint8_t*)buf, strlen(buf), 100);
			sprintf(buf, "          Options: -s\r\n");
			HAL_UART_Transmit(dev->uart, (uint8_t*)buf, strlen(buf), 100);
			sprintf(buf, "          Instructions: --duty, --freq");
			HAL_UART_Transmit(dev->uart, (uint8_t*)buf, strlen(buf), 100);

			sprintf(buf, "\r\n");
			HAL_UART_Transmit(dev->uart, (uint8_t*)buf, strlen(buf), 100);

			HAL_UART_Transmit(dev->uart, (uint8_t*)buf, strlen(buf), 100);
			sprintf(buf, "          temp -<OPTION> --<INSTRUCTION>\r\n");
			HAL_UART_Transmit(dev->uart, (uint8_t*)buf, strlen(buf), 100);
			sprintf(buf, "          Options: -m\r\n");
			HAL_UART_Transmit(dev->uart, (uint8_t*)buf, strlen(buf), 100);
			sprintf(buf, "          Instructions: --cont, --single\r\n");
			HAL_UART_Transmit(dev->uart, (uint8_t*)buf, strlen(buf), 100);

			sprintf(buf, "\r\n");
			HAL_UART_Transmit(dev->uart, (uint8_t*)buf, strlen(buf), 100);

			sprintf(buf, "          start -<OPTION> --<INSTRUCTION>\r\n");
			HAL_UART_Transmit(dev->uart, (uint8_t*)buf, strlen(buf), 100);
			sprintf(buf, "          Options: -p\r\n");
			HAL_UART_Transmit(dev->uart, (uint8_t*)buf, strlen(buf), 100);
			sprintf(buf, "          Instructions: --nonleaded, --leaded\r\n");
			HAL_UART_Transmit(dev->uart, (uint8_t*)buf, strlen(buf), 100);


			fsm->state = RFO_IDLE;
			break;

		}


	}
	/* USER CODE END 3 */
}

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
/* USER CODE BEGIN 4 */

void HAL_UART_TxCpltCallback(UART_HandleTypeDef *huart) {
	dp->trmRdy = 1;
}

void HAL_UART_RxCpltCallback(UART_HandleTypeDef *huart)
{
	if(huart->Instance == LPUART1){
		if(HAL_UART_Transmit(dev->uart, dev->rcv, 1, 1000) == HAL_OK) {
			fsm->state = RFO_PROCESS_CMD;
			HAL_UART_Receive_IT(dev->uart, dev->rcv, 1);
		}
	}
	else if(huart->Instance == USART1)  {

		nextion_decode_response(dp);

		switch(dp->response.page) {
		case DP_MAIN:  // page num main
			switch(dp->response.id) {
			case 2: // id of start button
				beep_IT(dev,3);
				PIDController_Init(pid, kP, kI, kD, SAMPLE_TIME, tau, limMin, limMax, limMinInt, limMaxInt);
				__HAL_TIM_SET_AUTORELOAD(&htim1, reflowARR);
				dp->write(dp, "page reflow");
				dp->write_id_str(dp, "conState", "Not connected");
				dp->write_id_str(dp, "reflowState", "Prepare");
				dp->write_id_val(dp, "reflowProgress", 0);
				fsm->state = RFO_START;
				dev->currentReflowState = REFLOW_STATE_PREPARE;
				dev->print = true;
				HAL_TIM_Base_Start_IT(&htim16);
				break;
			case 3: // id of settings button
				beep_IT(dev,1);
				dp->write(dp, "page setting");
				dev->currentPage = DP_SETTINGS;
				break;
			}
			break;

			case DP_SETTINGS: // page num settings
				switch(dp->response.id) {
				case 2: // id of back arrow button
					dp->write(dp, "page main");
					dev->currentPage = DP_MAIN;
					nextion_print_page(dp);
					break;
				case 3: // id of modeBT button
					beep_IT(dev,1);
					break;
				case 5: // id of apply button
					beep_IT(dev,2);
					if(dp->response.data == RFO_MODE_REFLOW) {
						PIDController_Init(pid, kP, kI, kD, SAMPLE_TIME, tau, limMin, limMax, limMinInt, limMaxInt);
						__HAL_TIM_SET_AUTORELOAD(&htim1, reflowARR);
						dp->write(dp, "page main");
						dev->currentPage = DP_MAIN;
						nextion_print_page(dp);
					}
					else if(dp->response.data == RFO_MODE_PLA) {
						PIDController_Init(pid, plaKp, plaKi, plaKd, SAMPLE_TIME, tau, limMin, limMax, limMinInt, limMaxInt);
						__HAL_TIM_SET_AUTORELOAD(&htim1, plaARR);
						dp->write(dp, "page mainPLA");
						dev->currentPage = DP_MAINPLA;
						dev->targetTemp = plaTemp;
						dp->write_id_float(dp, "plaTargetTemp", plaTemp);
						dp->write_id_float(dp, "t2", plaDuration);
					}
					break;
				}
				break;

				case 3:
					switch(dp->response.id) {
					case 15: // id of abort button
						beep_IT(dev,3);
						HAL_TIM_Base_Stop_IT(&htim16);
						dev->currentReflowState = REFLOW_STATE_IDLE;
						fsm->state = RFO_IDLE;
						dev->elaps = 0;
						__HAL_TIM_SET_COMPARE(&htim1, TIM_CHANNEL_1, 0);
						__HAL_TIM_SET_COMPARE(&htim1, TIM_CHANNEL_2, 0);
						dp->write(dp, "page main");
						dev->currentPage = DP_MAIN;
						nextion_print_page(dp);
						break;
					}
					break;
					case DP_MAINPLA:
						switch(dp->response.id) {
						case 2: // id of start button
							beep_IT(dev,3);
							dp->write(dp, "page filament");
							dp->write_id_str(dp, "temp", "0");
							dp->write_id_str(dp, "dur", "0");
							dp->write_id_val(dp, "j0", 0);
							fsm->state = RFO_START;
							dev->currentReflowState = REFLOW_STATE_PLA;
							dev->print = true;
							HAL_TIM_Base_Start_IT(&htim16);
							break;
						case 3: // id of settings button
							beep_IT(dev,1);
							dp->write(dp, "page setting");
							dev->currentPage = DP_SETTINGS;
							break;
						}
						break;
						case 4:
							switch(dp->response.id) {
							case 4: // id of PLA abort button
								beep_IT(dev,3);
								HAL_TIM_Base_Stop_IT(&htim16);
								dev->currentReflowState = REFLOW_STATE_IDLE;
								fsm->state = RFO_IDLE;
								dev->elaps = 0;
								__HAL_TIM_SET_COMPARE(&htim1, TIM_CHANNEL_1, 0);
								__HAL_TIM_SET_COMPARE(&htim1, TIM_CHANNEL_2, 0);
								dp->write(dp, "page mainPLA");
								dev->currentPage = DP_MAINPLA;
								dp->write_id_float(dp, "plaTargetTemp", plaTemp);
								dp->write_id_float(dp, "t2", plaDuration);
								break;
							}
							break;
							break;

		}

		HAL_UART_Receive_IT(&huart1, dp->rcv, 4);
	}
}
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

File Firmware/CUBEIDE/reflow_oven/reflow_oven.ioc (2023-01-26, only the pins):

Mcu.UserName=STM32WB55RGVx
PA1.Signal=SPI1_SCK
PA10.Signal=USART1_RX
PA13.Signal=SYS_JTMS-SWDIO
PA14.Signal=SYS_JTCK-SWCLK
PA2.Signal=LPUART1_TX
PA3.Signal=LPUART1_RX
PA4.GPIO_Label=NSS
PA4.Signal=GPIO_Output
PA5.GPIO_Label=Buzzer
PA5.Signal=S_TIM2_CH1
PA6.Signal=SPI1_MISO
PA8.Signal=S_TIM1_CH1
PA9.Signal=S_TIM1_CH2
PB0.GPIO_Label=LED_GREEN
PB0.Signal=GPIO_Output
PB6.Signal=USART1_TX

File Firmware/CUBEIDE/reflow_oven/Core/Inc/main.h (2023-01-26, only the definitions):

#define NSS_Pin GPIO_PIN_4
#define NSS_GPIO_Port GPIOA
#define Buzzer_Pin GPIO_PIN_5
#define Buzzer_GPIO_Port GPIOA
#define LED_GREEN_Pin GPIO_PIN_0
#define LED_GREEN_GPIO_Port GPIOB

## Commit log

2022-04-21 Added current src files
    [2047110001.stp, 2450AT14A0100T.stp, A-1JB.step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]
2022-04-21 Changed PCB dir name
    [2047110001.stp, 2450AT14A0100T.stp, A-1JB.step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]
2022-04-22 PCB antenna removed
    [MLPF-WB55-01E3.stp, reflowControllerV2.kicad_pcb, reflowControllerV2.kicad_sch]
2022-04-23 Further component placing
    [M830520.stp, reflowControllerV2.kicad_pcb, reflowControllerV2.kicad_sch]
2022-04-26 RF Routing, Guard Ring, component placing, switching to mosfets
    [reflowControllerV2.kicad_pcb, reflowControllerV2.kicad_sch]
2022-04-27 Started layout, critical sections first
    [reflowControllerV2.kicad_pcb, reflowControllerV2.kicad_sch]
2022-04-27 Layout done, improovements needed
    [reflowControllerV2.kicad_pcb, reflowControllerV2.kicad_sch]
2022-04-29 PCB finalized, Gerbers created, Firmware dir renamed
    [reflowControllerV2-B_Cu.gbr, reflowControllerV2-B_Mask.gbr, reflowControllerV2-B_Paste.gbr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]
2022-04-29 Recreated Gerbers with removed order number
    [reflowControllerV2-B_Cu.gbr, reflowControllerV2-B_Mask.gbr, reflowControllerV2-B_Paste.gbr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]
2022-05-04 Added loading, main, setting and reflow page, modfied uart callbacks
2022-05-04 PCB backup
2022-05-04 Removed old MATLAB code, not longer needed
    [temp_test1.csv]
2022-05-26 Added 3d models for printing front and accessories
    [button.stl, led.stl, smartReflowFront.stl]
2022-05-26 Added current Firmware version in CubeIDE
2022-05-26 Backups, step model of PCB
2022-06-13 PLA heating and 160 deg paste working reliably
2022-06-13 PLA heating page added
2022-06-13 Few changes
    [reflowControllerV2.kicad_pcb, reflowControllerV2.kicad_sch]
2022-06-13 Added pictures of PCB, mechanicals and results
2022-06-23 Assembly information
2022-08-06 Reorganized schematic
    [reflowControllerV2.kicad_pcb, reflowControllerV2.kicad_sch]

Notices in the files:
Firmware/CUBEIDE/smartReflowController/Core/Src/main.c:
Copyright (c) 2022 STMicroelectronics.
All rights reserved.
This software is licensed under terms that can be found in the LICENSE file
